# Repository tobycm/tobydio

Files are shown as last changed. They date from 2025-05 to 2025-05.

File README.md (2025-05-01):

# tobydio - a breakout board for developing with DAC and ADC ICs

A semi-assembled board to develop with DAC and ADC from chip makers like TI. Featuring a line in and line out 3.5mm headphone jack to receive and output sound signal, pin headers to interface with microcontrollers, and awesome art. 

Cost: $33.87

This is my fourth pcb ever. I developed this during my pixeldust ysws where I wanted to incorporate some audio system in my project and this is one way for me to test subsystems. I learned how to find and source parts from suppliers like DigiKey, LCSC. I also learned how to get symbols, footprints, and models to help my development process.

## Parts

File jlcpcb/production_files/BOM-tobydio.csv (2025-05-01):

Comment | Designator | Footprint | LCSC | Quantity
PCM5100APWR | U1 | PW0020A | C131154 | 1
0.1uF | C1,C13,C15,C17,C2,C3,C4 | C_0402_1005Metric_Pad0.74x0.62mm_HandSolder | C1525 | 7
10uF | C10,C16,C7,C8,C9 | C_0402_1005Metric_Pad0.74x0.62mm_HandSolder | C15525 | 5
PJ-320D-A | J2,J8 | HRO_PJ-320D-A | C19189088 | 2
10uF | C14,C18 | C_0603_1608Metric_Pad1.08x0.95mm_HandSolder | C19702 | 2
LED | D1 | LED_0805_2012Metric_Pad1.15x1.40mm_HandSolder | C2297 | 1
2.2uF | C5,C6 | C_0603_1608Metric_Pad1.08x0.95mm_HandSolder | C23630 | 2
220 | R5 | R_0402_1005Metric_Pad0.72x0.64mm_HandSolder | C25091 | 1
470 | R1,R2,R3,R4 | R_0402_1005Metric_Pad0.72x0.64mm_HandSolder | C25117 | 4
2.2nF | C11,C12,C21,C22 | C_0805_2012Metric_Pad1.18x1.45mm_HandSolder | C28260 | 4
1uF | C19,C20 | C_0805_2012Metric_Pad1.18x1.45mm_HandSolder | C28323 | 2
PCM1808PWR | U2 | PW14 | C55513 | 1

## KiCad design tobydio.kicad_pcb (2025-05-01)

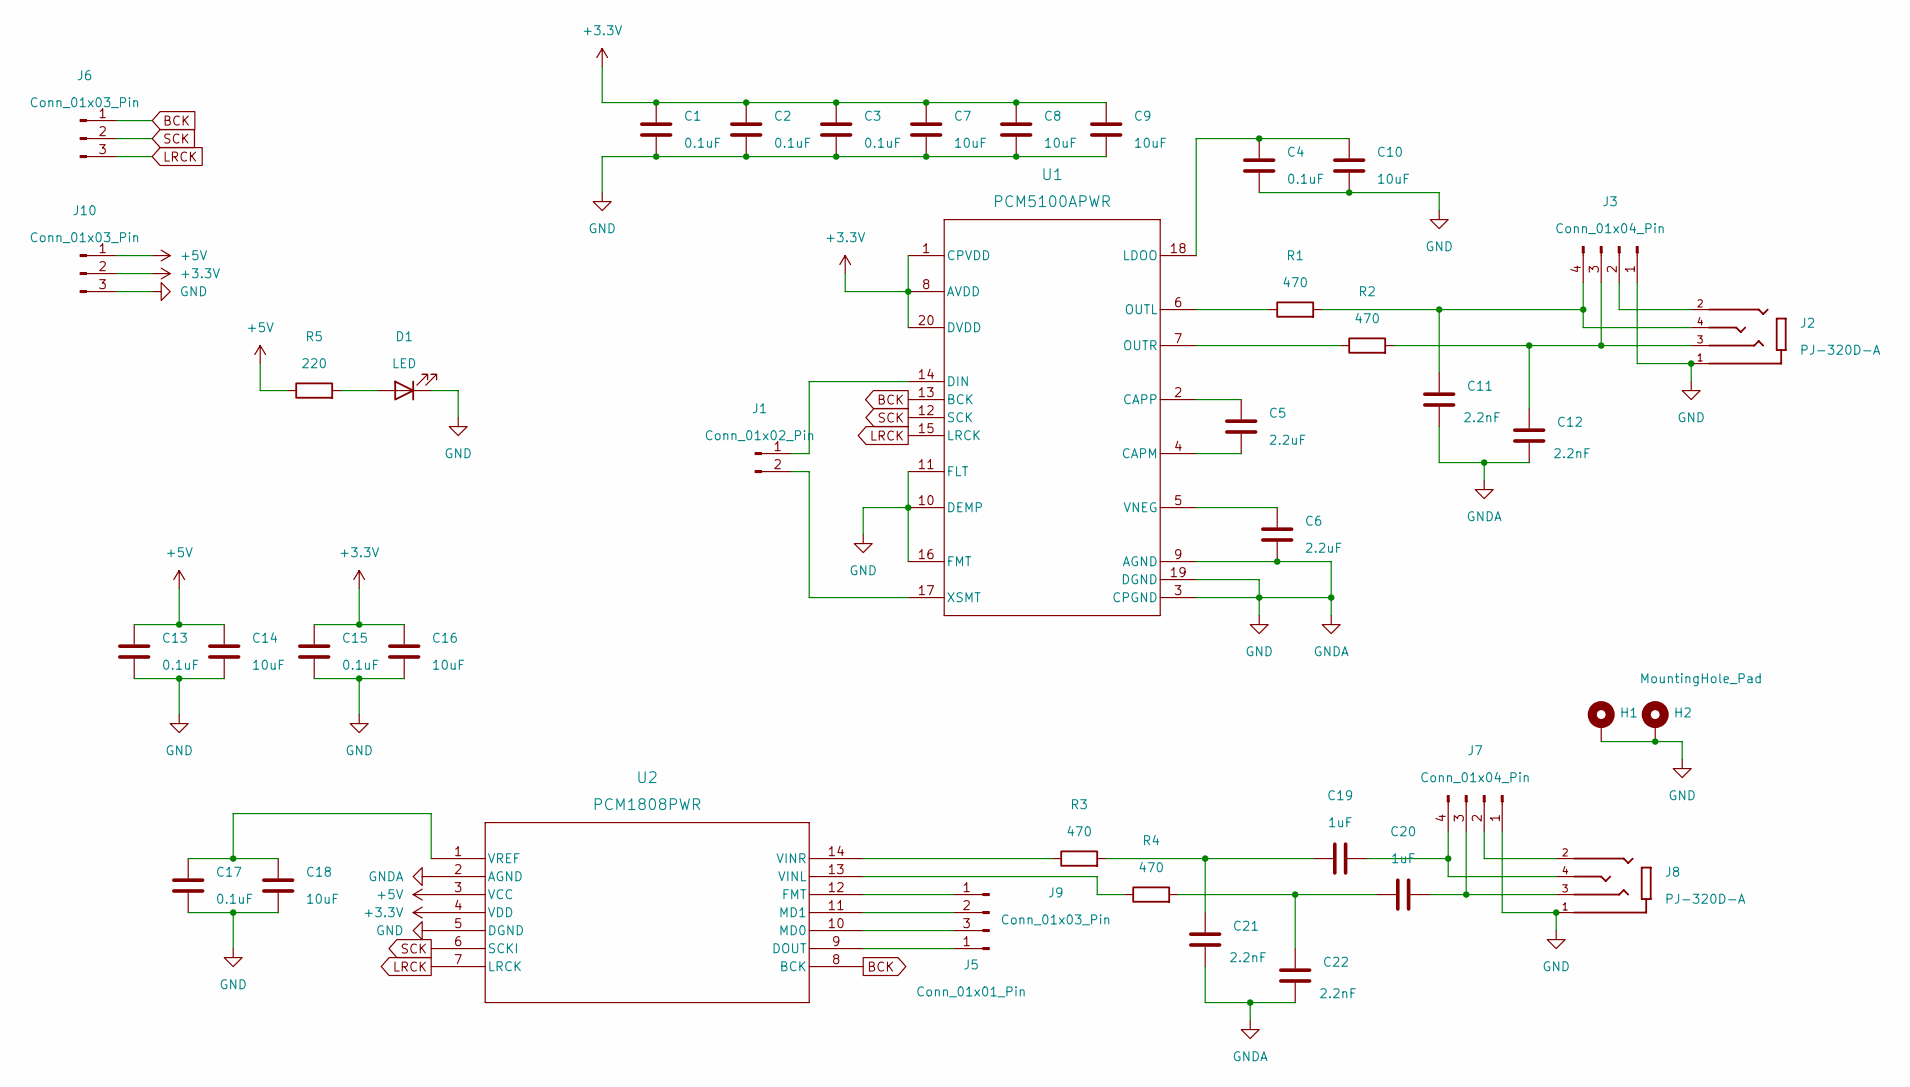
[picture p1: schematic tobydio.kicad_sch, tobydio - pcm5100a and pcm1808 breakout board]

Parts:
C1, C2, C3, C4, C13, C15, C17: 0.1uF; C_0402_1005Metric_Pad0.74x0.62mm_HandSolder; LCSC Part # C1525
C5, C6: 2.2uF; C_0603_1608Metric_Pad1.08x0.95mm_HandSolder; LCSC Part # C23630
C7, C8, C9, C10, C16: 10uF; C_0402_1005Metric_Pad0.74x0.62mm_HandSolder; LCSC Part # C15525
C11, C12, C21, C22: 2.2nF; C_0805_2012Metric_Pad1.18x1.45mm_HandSolder; LCSC Part # C28260
C14, C18: 10uF; C_0603_1608Metric_Pad1.08x0.95mm_HandSolder; LCSC Part # C19702
C19, C20: 1uF; C_0805_2012Metric_Pad1.18x1.45mm_HandSolder; LCSC Part # C28323
D1: LED; LED_0805_2012Metric_Pad1.15x1.40mm_HandSolder; LCSC Part # C2297
H1, H2: MountingHole_Pad; MountingHole_4.3mm_M4_Pad_Via
J1: Conn_01x02_Pin; PinHeader_1x02_P2.54mm_Vertical
J2, J8: PJ-320D-A; HRO_PJ-320D-A; PARTREV B
J3, J7: Conn_01x04_Pin; PinHeader_1x04_P2.54mm_Vertical
J5: Conn_01x01_Pin; PinHeader_1x01_P2.54mm_Vertical
J6, J9, J10: Conn_01x03_Pin; PinHeader_1x03_P2.54mm_Vertical
R1, R2, R3, R4: 470; R_0402_1005Metric_Pad0.72x0.64mm_HandSolder; LCSC Part # C25117
R5: 220; R_0402_1005Metric_Pad0.72x0.64mm_HandSolder; LCSC Part # C25091
U1: PCM5100APWR; PW0020A
U2: PCM1808PWR; PW14

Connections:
+3.3V: C1.1, C2.1, C3.1, C7.1, C8.1, C9.1, C15.1, C16.1, J10.2, U1.1 (CPVDD), U1.8 (AVDD), U1.20 (DVDD), U2.4 (VDD)
+5V: C13.1, C14.1, J10.1, R5.1, U2.3 (VCC)
BCK: J6.1, U1.13 (BCK), U2.8 (BCK)
GND: C1.2, C2.2, C3.2, C4.2, C6.2, C7.2, C8.2, C9.2, C10.2, C11.2, C12.2, C13.2, C14.2, C15.2, C16.2, C17.2, C18.2, C21.2, C22.2, D1.1 (K), H1.1, H2.1, J2.1, J3.1, J7.1, J8.1, J10.3, U1.3 (CPGND), U1.9 (AGND), U1.10 (DEMP), U1.11 (FLT), U1.16 (FMT), U1.19 (DGND), U2.2 (AGND), U2.5 (DGND)
LRCK: J6.3, U1.15 (LRCK), U2.7 (LRCK)
unnamed: C19.1, C21.1, R3.2
unnamed: C20.1, C22.1, R4.2
unnamed: D1.2 (A), R5.2
unnamed: J1.1, U1.14 (DIN)
unnamed: J1.2, U1.17 (XSMT)
unnamed: J2.2, J3.2
unnamed: C12.1, J2.3, J3.3, R2.2
unnamed: C11.1, J2.4, J3.4, R1.2
unnamed: J5.1, U2.9 (DOUT)
unnamed: J7.2, J8.2
unnamed: C20.2, J7.3, J8.3
unnamed: C19.2, J7.4, J8.4
unnamed: J9.1, U2.12 (FMT)
unnamed: J9.2, U2.11 (MD1)
unnamed: J9.3, U2.10 (MD0)
unnamed: C5.2, U1.4 (CAPM)
unnamed: C5.1, U1.2 (CAPP)
unnamed: C4.1, C10.1, U1.18 (LDOO)
unnamed: R1.1, U1.6 (OUTL)
unnamed: R2.1, U1.7 (OUTR)
unnamed: C6.1, U1.5 (VNEG)
unnamed: R4.1, U2.13 (VINL)
unnamed: R3.1, U2.14 (VINR)
unnamed: C17.1, C18.1, U2.1 (VREF)
SCK: J6.2, U1.12 (SCK), U2.6 (SCKI)

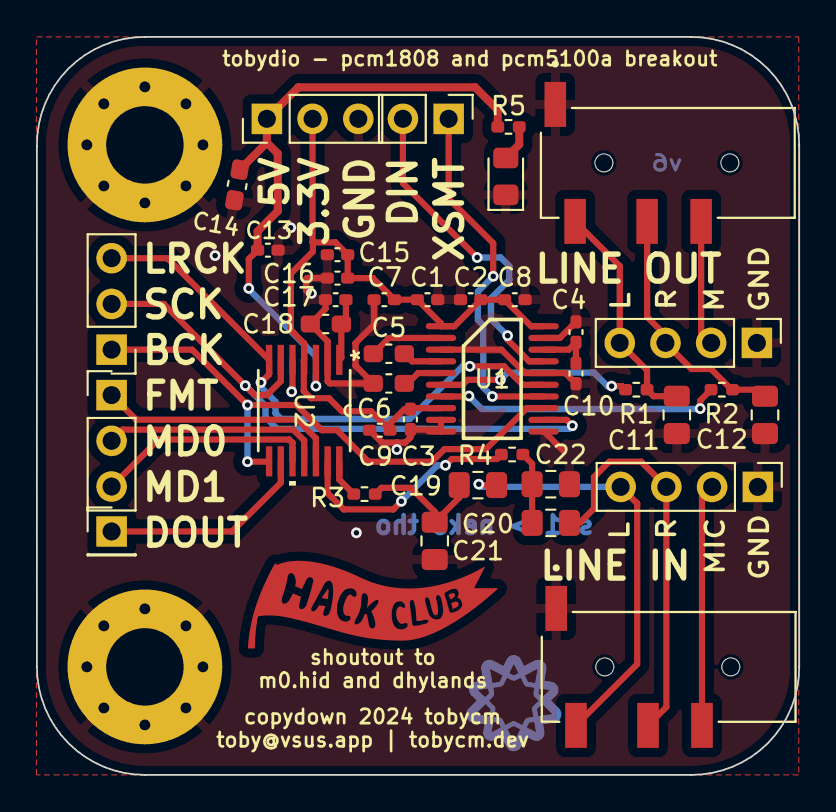
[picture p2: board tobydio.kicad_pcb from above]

Board: 2 copper layers, 42.4 x 41.0 mm, 41 parts (0 on the bottom side), 30 nets.
